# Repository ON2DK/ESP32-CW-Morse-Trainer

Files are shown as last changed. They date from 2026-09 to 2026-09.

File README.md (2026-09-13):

# ESP32 CW Morse Trainer V2

Open-source ESP32 Morse/CW trainer designed by **ON2DK**.

The ESP32 CW Morse Trainer V2 is a stand-alone Morse trainer built around a **38-pin ESP32 DevKit with ESP32-WROOM-32D**. It is intended for CW practice without connecting a transceiver.

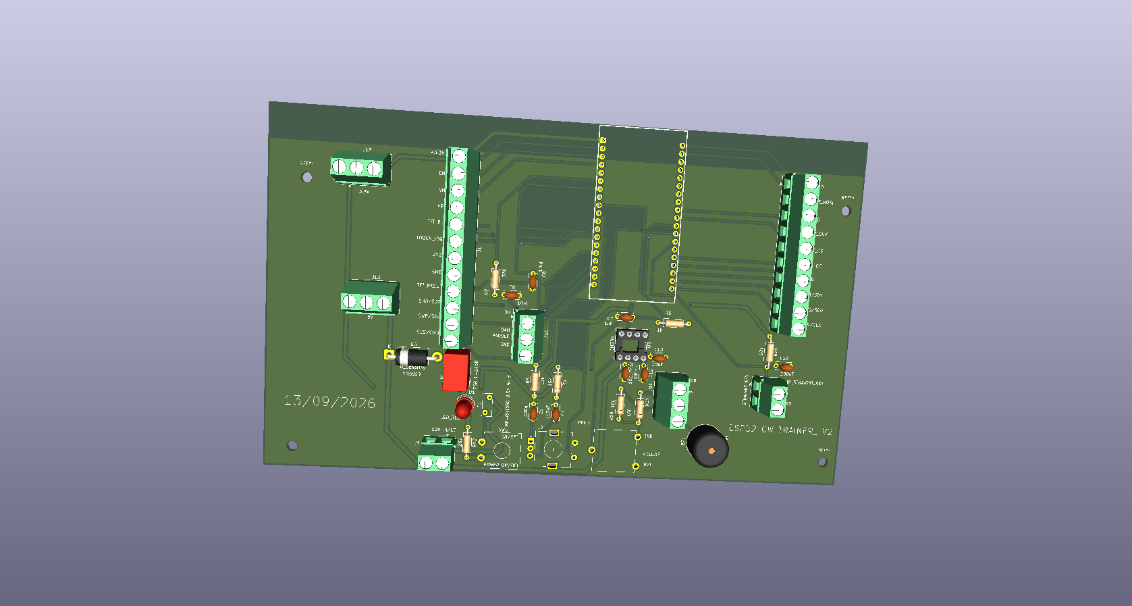
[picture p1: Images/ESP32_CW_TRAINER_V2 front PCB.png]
ESP32 CW Trainer V2 front PCB


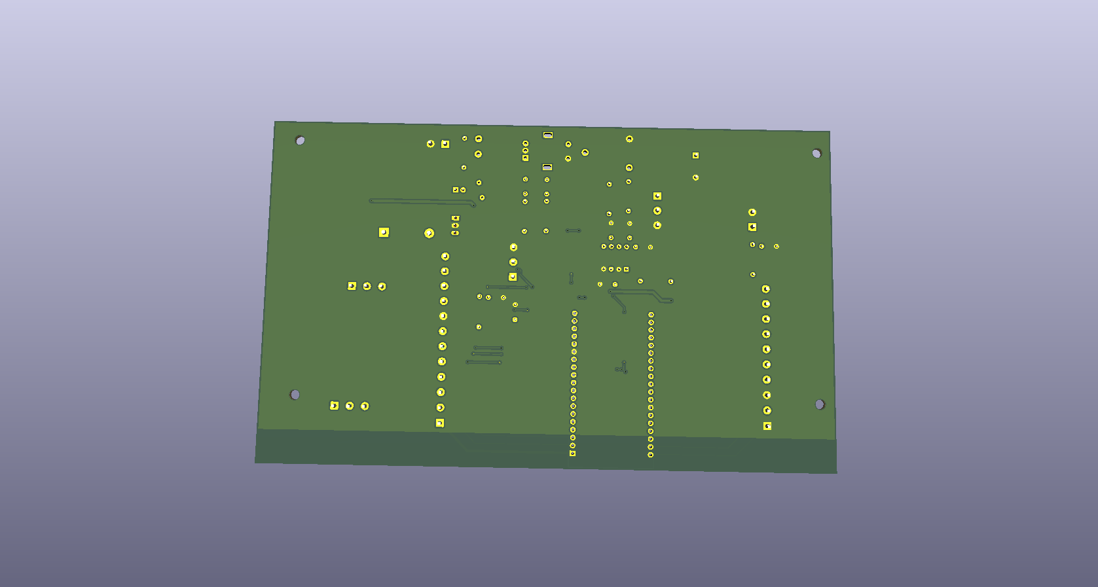
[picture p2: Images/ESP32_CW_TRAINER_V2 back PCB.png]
ESP32 CW Trainer V2 back PCB


## Main features

- 38-pin ESP32 DevKit with ESP32-WROOM-32D
- ST7789 240 x 320 SPI TFT support
- Paddle input
- Straight-key input
- Rotary encoder with push switch for menu/settings
- LM386 audio/sidetone section with buzzer
- Free CW practice
- Koch training
- Lesson selection and visible Koch characters
- Session score and total score
- Student profile/settings stored in ESP32 Preferences
- Separate 12 V DC input
- TSR 1-2450 12 V to 5 V DC/DC converter
- POWER LED on the switched 12 V supply
- USB on the ESP32 DevKit for programming
- Predominantly through-hole construction

## PCB status

The hardware design is complete and the final PCB was checked in KiCad before generating the production files.

- 2-layer PCB: F.Cu + B.Cu
- Target material: FR-4, 1.6 mm
- PCB size: approximately **189.25 x 114.50 mm**
- 4 x M3 mounting holes
- KiCad DRC: **0 violations / 0 errors / 0 warnings** at final electrical check
- Unconnected items: **0**
- Schematic/PCB parity: **0**

## Downloads and repository structure

- `KiCad/` - editable KiCad source package: `ESP32_CW_TRAINER_V2_KiCad_Source.zip`
- `Gerber/` - production package: `ESP32_CW_TRAINER_V2_Gerber.zip`
- `Firmware/` - Arduino IDE firmware and firmware notes
- `Enclosure/` - STL files for front panel, rear panel, bottom and lid, plus editable OpenSCAD source
- `Documentation/` - project logbook, BOM and build notes
- `Images/` - front and back PCB images

## Firmware

The V2 Arduino IDE firmware is available as:

- `Firmware/ESP32_CW_TRAINER_V2.ino`

The firmware has been reconciled with the definitive Trainer V2 PCB GPIO mapping and includes ST7789 display support, rotary-encoder control, paddle input, straight-key input, sidetone/audio and the existing Morse Trainer functions such as free practice, Koch training, lessons, scores and Preferences storage.

### Definitive V2 GPIO mapping

| Function | ESP32 GPIO |
|---|---:|
| TFT SCK | 18 |
| TFT MOSI | 23 |
| TFT DC | 2 |
| TFT RESET | 13 |
| TFT CS | 5 |
| TFT BACKLIGHT | 27 |
| Encoder CLK | 16 |
| Encoder DT | 17 |
| Encoder SW | 26 |
| Paddle DIT | 35 |
| Paddle DAH | 32 |
| Straight key | 4 |
| Audio / buzzer | 25 |

**GPIO35 is input-only and does not provide an internal pull-up. The Trainer V2 hardware must therefore provide the required external input bias for the DIT input.**

The current V2 firmware was successfully **compiled/verified in Arduino IDE on 13 September 2026** with **ESP32 Dev Module** selected. Arduino IDE reported approximately:

- Program storage: **1,014,070 bytes (77%)**
- Dynamic memory: **49,416 bytes (15%)**
- Dynamic memory remaining for local variables: approximately **278,264 bytes**

Successful compilation confirms that the current sketch builds with the installed ESP32/Arduino libraries. It does **not** replace practical testing on the assembled Trainer V2 PCB.

## Enclosure files

The enclosure folder contains the current mechanical design for the CW Trainer V2, including a front-panel opening for the 2.8-inch TFT so that only the display area is visible.

Current files include:

- `ESP32_CW_TRAINER_V2_Frontpaneel.stl`
- `ESP32_CW_TRAINER_V2_Achterpaneel.stl`
- `ESP32_CW_TRAINER_V2_Kast_Bodem.stl`
- `ESP32_CW_TRAINER_V2_Kast_Deksel.stl`
- `ESP32_CW_TRAINER_V2_Kast.scad`

The TFT opening should be checked against the exact physical TFT module before final printing.

## Documentation

The final project logbook with BOM is available under `Documentation/` as:

`ESP32_CW_TRAINER_V2_Projectlogboek_DEFINITIEF_MET_BOM.docx`

## Production files

Before ordering a PCB, inspect the Gerbers in a Gerber viewer and verify board outline, drill files, silkscreen, masks and both copper layers.

## Power and programming

Normal operation uses the separate **12 V DC input**. The on-board USB connector of the ESP32 DevKit is intended for programming.

During USB programming, switch the external 12 V supply **OFF**.

Power path:

`12 V DC -> 0.5 A polyfuse -> POWER switch -> TSR 1-2450 -> 5 V -> ESP32 DevKit`

The red POWER LED is connected to the switched 12 V side, so it only lights when the main power switch is ON.

## Important build notes

Always compare the physical pinout and dimensions of purchased components with the KiCad footprints before soldering. In particular, check polarity of LEDs, diodes and electrolytic capacitors, connector orientation and pin order, transistor pinouts, ESP32 DevKit orientation and clear space around the ESP32 antenna area.

Test the 5 V supply before fitting sensitive modules such as the ESP32 and TFT.

## Project status

- Hardware V2: complete / production files prepared
- KiCad electrical checks: passed
- Enclosure: available; final TFT fit to be verified
- Documentation/BOM: available
- V2 firmware: compiles successfully with definitive GPIO mapping
- Practical assembled-PCB firmware/hardware testing: pending

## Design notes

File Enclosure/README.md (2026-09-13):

# Enclosure

This folder is reserved for the 3D-printable enclosure and OpenSCAD source files for the ESP32 CW Morse Trainer V2.

The PCB uses four M3 mounting holes. Before printing a final enclosure, verify the exact dimensions of the physical TFT module, panel connectors, rotary encoder and potentiometer.

The ESP32 antenna area should remain clear of metal and dense wiring inside the enclosure.

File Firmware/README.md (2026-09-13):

# Firmware

Arduino IDE firmware for the ESP32 CW Morse Trainer belongs in this folder.

The hardware is intended for a 38-pin ESP32 DevKit with ESP32-WROOM-32D and an ST7789 240 x 320 SPI TFT.

Before flashing any sketch, verify that its GPIO definitions match the final KiCad PCB revision. Hardware and firmware should always be treated as a matched pair.

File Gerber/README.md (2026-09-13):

# Gerber production files

Current production package:

`ESP32_CW_TRAINER_V2_Gerber.zip`

The package is intended for a 2-layer FR-4 PCB and should contain the copper, solder mask, silkscreen, board outline and drill files required for fabrication.

Before ordering, inspect the archive in a Gerber viewer and verify the board outline, connector labels, mounting holes and PTH/NPTH drill data.

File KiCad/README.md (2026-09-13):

# KiCad source

This folder contains the editable KiCad source package for the ESP32 CW Morse Trainer V2.

Current source archive:

`ESP32_CW_TRAINER_V2_KiCad_Source.zip`

The project uses a 38-pin ESP32 DevKit with ESP32-WROOM-32D. When opening the project on another computer, verify that project-local footprint libraries are available and that KiCad does not replace intentionally selected footprints without review.

After any PCB edit, refill copper zones and rerun DRC and schematic/PCB parity checks before regenerating Gerbers.

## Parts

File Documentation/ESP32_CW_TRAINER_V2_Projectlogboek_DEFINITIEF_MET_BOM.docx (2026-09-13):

PROJECTLOGBOEK
ESP32 CW MORSE TRAINER V2

Definitieve hardware-revisie • 13 september 2026

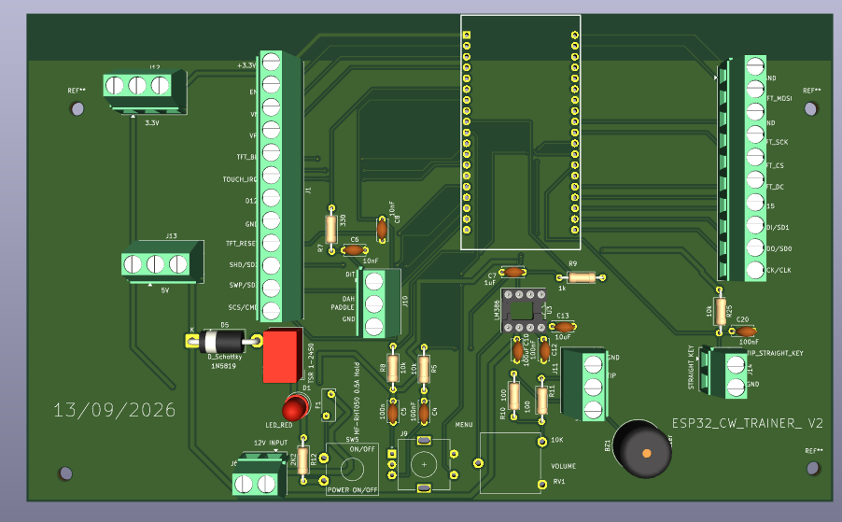
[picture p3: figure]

# 1. Projectdoel

Zelfstandige CW/Morse-trainer rond een 38-pins ESP32 DevKit met ESP32-WROOM-32D. De print ondersteunt TFT, rotary encoder/menu, paddle, straight key en audio via LM386/buzzer. De normale voeding gebeurt via een afzonderlijke 12 V ingang; USB-C op de DevKit is bedoeld voor programmeren.

# 2. Productiestatus

Controle | Status
PCB DRC | 0 overtredingen / 0 fouten / 0 waarschuwingen
Niet-verbonden items | 0
Schema-pariteit | 0
PCB-afmeting | 189,25 × 114,50 mm
Montagegaten | 4 × M3
Silkscreen | ESP32_CW_TRAINER_V2 • 13/09/2026
Gerberpakket | Definitieve F/B Cu, mask, silkscreen, Edge.Cuts, PTH en NPTH

# 3. Laatste PCB-revisie

Na het eerdere logboek zijn de projectbenaming op de PCB-silkscreen geplaatst en BZ1 (buzzer) verplaatst om de aansluiting beter bereikbaar te maken. De nieuwe PCB-afbeeldingen en productiebestanden horen bij deze revisie.

# 4. Voeding en programmering

12 V DC → F1 0,5 A polyfuse → POWER ON/OFF → TSR 1-2450 → 5 V naar de ESP32 DevKit. De rode POWER-led zit op de geschakelde 12 V zijde via R12 = 2,2 kΩ. Tijdens programmeren via USB wordt de 12 V hoofdvoeding uitgeschakeld.

# 5. ESP32-signaaltoewijzing

Functie | GPIO
TFT_DC | GPIO2
STRAIGHT_KEY | GPIO4
TFT_CS | GPIO5
TFT_RESET | GPIO13
TOUCH_IRQ | GPIO14
ENC_A / ENC_B | GPIO16 / GPIO17
TFT_SCK / TFT_MOSI | GPIO18 / GPIO23
AUDIO | GPIO25
ENC_SW | GPIO26
TFT_BL | GPIO27
DAH / DIT | GPIO32 / GPIO35
BUTTON_ADC | GPIO34

# PCB-achterzijde

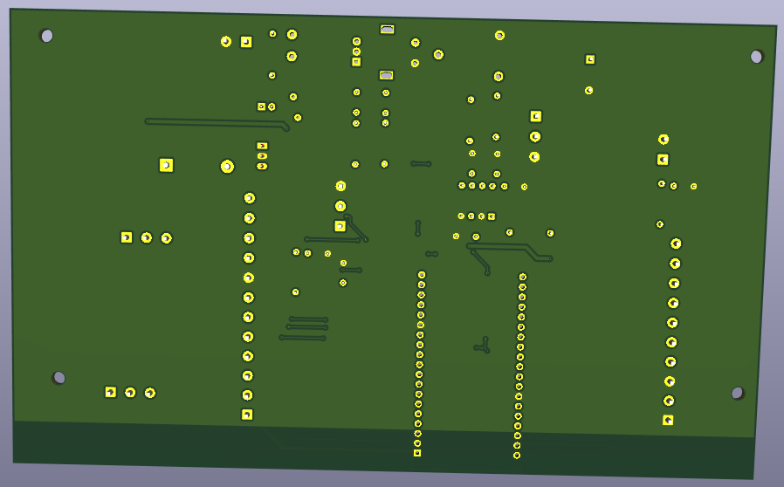
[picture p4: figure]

Definitieve 3D-weergave van de onderzijde van de ESP32 CW Morse Trainer V2.

# 6. Behuizing en assemblage

Het 3D-printbare kastpakket bevat bodem, deksel, frontpaneel, achterpaneel en OpenSCAD-bron. Controleer de werkelijk aangekochte paneelconnectoren mechanisch vóór de definitieve print. Test eerst de 5 V voeding zonder ESP32, plaats daarna de DevKit en test TFT, encoder, paddle/straight key en audio stapsgewijs.

# 7. Archivering

Bewaar samen: definitieve KiCad-bronbestanden, projectlokale ESP32_DevKit-footprintbibliotheek, Gerber/Drill-pakket, dit logboek, kastbestanden en de voor-/achteraanzichtafbeeldingen.

# 8. Componentenlijst (BOM)

Componentenlijst volgens het KiCad-schema. Controleer vóór assemblage de fysieke afmetingen en pinout van het werkelijk aangekochte onderdeel tegen de gekozen footprint.

Aantal | Referentie(s) | Waarde / onderdeel | KiCad-footprint
1 | BZ1 | Buzzer | Buzzer_Beeper:Buzzer_12x9.5RM7.6
1 | C4 | 100nF | Capacitor_THT:C_Disc_D5.0mm_W2.5mm_P5.00mm
1 | C5 | 100n | Capacitor_THT:C_Disc_D5.0mm_W2.5mm_P5.00mm
2 | C6, C8 | 10nF | Capacitor_THT:C_Disc_D5.0mm_W2.5mm_P5.00mm
1 | C7 | 1uF | Capacitor_THT:C_Disc_D5.0mm_W2.5mm_P5.00mm
1 | C10 | 100uF | Capacitor_THT:C_Disc_D5.0mm_W2.5mm_P5.00mm
1 | C12 | 100nF | Capacitor_THT:C_Disc_D5.0mm_W2.5mm_P5.00mm
1 | C13 | 10uF | Capacitor_THT:C_Disc_D5.0mm_W2.5mm_P5.00mm
1 | C20 | 100nF | Capacitor_THT:C_Disc_D5.0mm_W2.5mm_P5.00mm
1 | D1 | LED_RED | LED_THT:LED_D5.0mm
1 | D5 | 1N5819 Schottky | Diode_THT:D_DO-201AD_P15.24mm_Horizontal
1 | F1 | MF-RHT050 0.5A Hold | Fuse:Fuse_Bourns_MF-RHT050
1 | J1 | Conn_01x12 | TerminalBlock_Phoenix:MKDS-1,5-12_1x12_P5.00mm_Horizontal
1 | J3 | Conn_01x10 | TerminalBlock_Phoenix:MKDS-1,5-10_1x10_P5.00mm_Horizontal
2 | J6, J14 | Conn_01x02 | TerminalBlock_Phoenix:MKDS-1,5-2_1x02_P5.00mm_Horizontal
1 | J9 | RotaryEncoder_Switch | Rotary_Encoder:RotaryEncoder_Alps_EC11E-Switch_Vertical_H20mm
4 | J10, J11, J12, J13 | Conn_01x03 | TerminalBlock_Phoenix:MKDS-1,5-3_1x03_P5.00mm_Horizontal
3 | R5, R8, R25 | 10k | Resistor_THT:R_Axial_DIN0207_L6.3mm_D2.5mm_P10.16mm_Horizontal
1 | R7 | 330 | Resistor_THT:R_Axial_DIN0207_L6.3mm_D2.5mm_P10.16mm_Horizontal
1 | R9 | 1k | Resistor_THT:R_Axial_DIN0207_L6.3mm_D2.5mm_P10.16mm_Horizontal
2 | R10, R11 | 100 | Resistor_THT:R_Axial_DIN0207_L6.3mm_D2.5mm_P10.16mm_Horizontal
1 | R12 | 2K2 | Resistor_THT:R_Axial_DIN0207_L6.3mm_D2.5mm_P10.16mm_Horizontal
1 | RV1 | 10K | Potentiometer_THT:Potentiometer_ACP_CA14V-15_Vertical
1 | SW5 | POWER ON/OFF | Button_Switch_THT:SW_CW_GPTS203211B
1 | U2 | ESP32-WROOM-32 / 38-pin DevKit | ESP32_DevKit:ESP32_DevKit_38P
1 | U3 | LM386 | Package_DIP:DIP-8_W7.62mm_Socket
1 | U6 | TSR 1-2450 | Converter_DCDC:Converter_DCDC_TRACO_TSR-1_THT

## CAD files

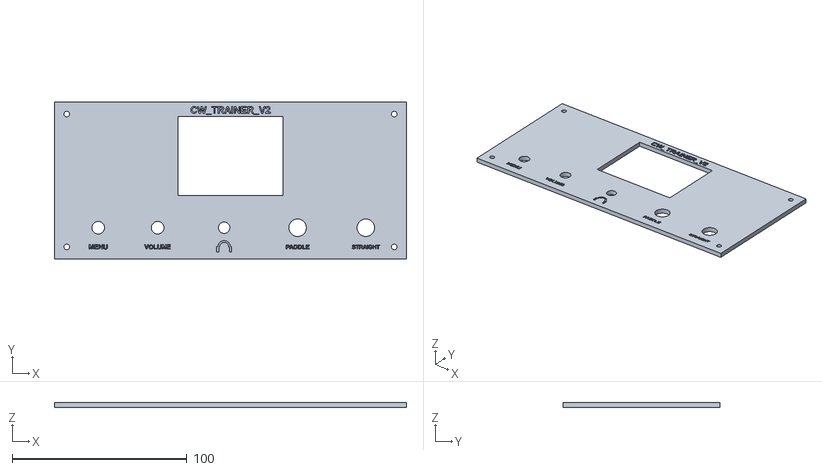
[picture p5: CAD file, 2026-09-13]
Enclosure/ESP32_CW_TRAINER_V2_Frontpaneel.stl
201.2 x 90.0 x 3.00

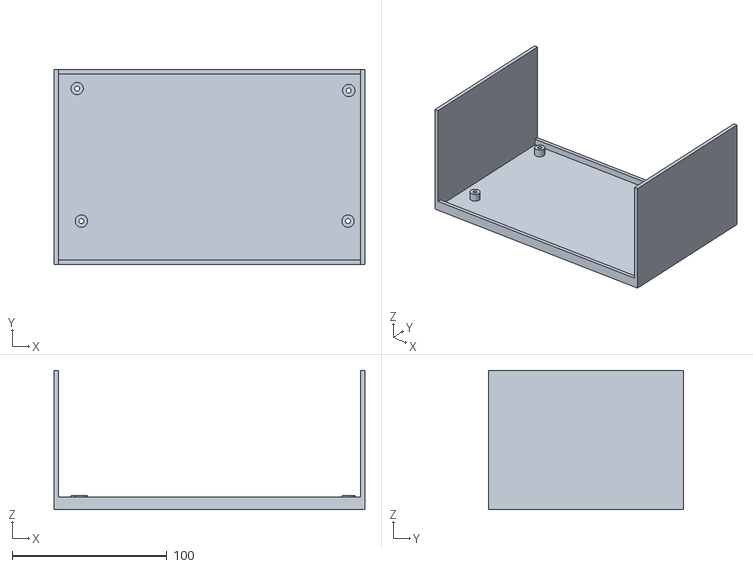
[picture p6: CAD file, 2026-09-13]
Enclosure/ESP32_CW_TRAINER_V2_Kast_Bodem.stl
201.2 x 126.5 x 90.0

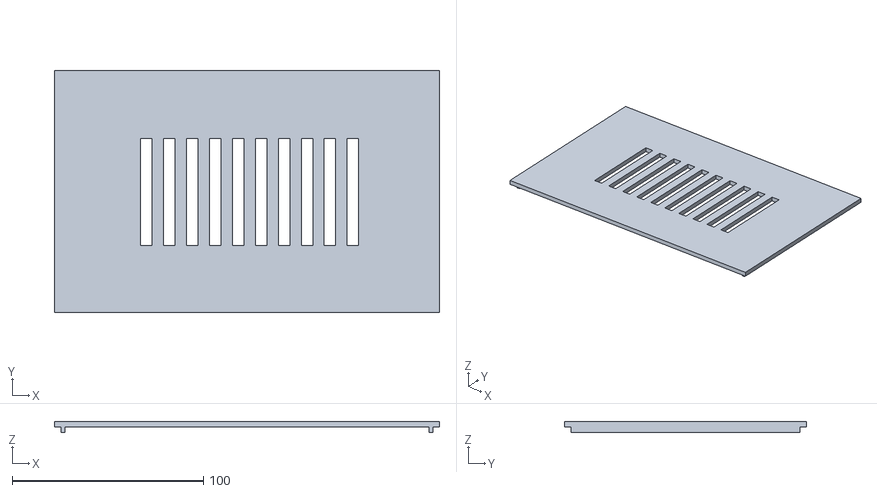
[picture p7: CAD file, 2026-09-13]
Enclosure/ESP32_CW_TRAINER_V2_Kast_Deksel.stl
201.2 x 126.5 x 6.00

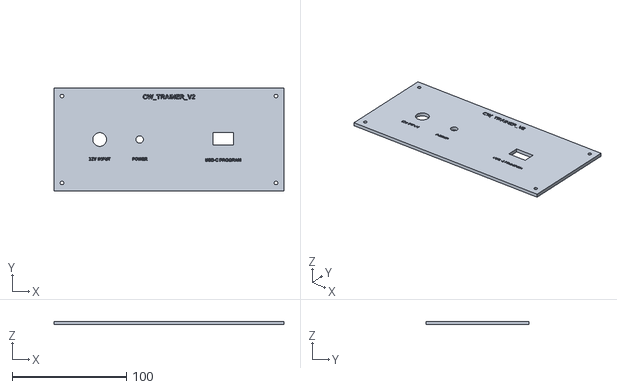
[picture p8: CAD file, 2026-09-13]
Enclosure/ESP32_CW_TRAINER_V2_Achterpaneel.stl
201.2 x 90.0 x 3.00

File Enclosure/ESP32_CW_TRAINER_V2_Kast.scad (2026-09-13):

$fn=72;

// ESP32 CW TRAINER V2 enclosure - revised front/rear panels
// TFT window is PARAMETRIC. Default 60 x 45 mm; verify against exact visible glass area.
pcb_w=189.25;
pcb_d=114.50;
clear=6;
wall=3;
bottom=3;
outer_w=pcb_w+2*clear;   // 201.25 mm
outer_d=pcb_d+2*clear;   // 126.50 mm
case_h=90;
panel_t=3;

tft_win_w=60.0;
tft_win_h=45.0;
tft_x=outer_w/2;
tft_y=59;
ctrl_y=18;

module base(){
    difference(){
        union(){
            cube([outer_w,outer_d,bottom]);
            cube([wall,outer_d,case_h]);
            translate([outer_w-wall,0,0]) cube([wall,outer_d,case_h]);
            cube([outer_w,wall,bottom+5]);
            translate([0,outer_d-wall,0]) cube([outer_w,wall,bottom+5]);
            for(p=[[9,108],[184.25,22.25],[11.75,22.25],[184.75,106.75]])
                translate([clear+p[0],clear+p[1],bottom]) cylinder(h=6,d=8);
        }
        for(p=[[9,108],[184.25,22.25],[11.75,22.25],[184.75,106.75]])
            translate([clear+p[0],clear+p[1],-0.1]) cylinder(h=bottom+6.2,d=3.2);
    }
}

module lid(){
    difference(){
        union(){
            cube([outer_w,outer_d,3]);
            translate([wall+0.4,wall+0.4,-3]) cube([2,outer_d-2*(wall+0.4),3]);
            translate([outer_w-wall-2.4,wall+0.4,-3]) cube([2,outer_d-2*(wall+0.4),3]);
        }
        for(x=[45:12:155]) translate([x,35,-0.1]) cube([6,56,3.2]);
    }
}

module engrave(txt,x,y,size=3.2) {
    translate([x,y,panel_t-0.7]) linear_extrude(height=0.8)
        text(txt,size=size,halign="center",valign="center",font="Liberation Sans:style=Bold");
}

module headphone_icon(x,y,s=1) {
    translate([x,y,panel_t-0.7]) linear_extrude(height=0.8) scale([s,s]) {
        union() {
            difference() {
                circle(r=5.0);
                circle(r=3.6);
                translate([-6,-6]) square([12,6]);
            }
            translate([-5.1,-1.8]) square([1.8,4.5],center=true);
            translate([ 5.1,-1.8]) square([1.8,4.5],center=true);
        }
    }
}

module front_panel(){
    difference(){
        cube([outer_w,case_h,panel_t]);

        translate([tft_x-tft_win_w/2,tft_y-tft_win_h/2,-0.1])
            cube([tft_win_w,tft_win_h,panel_t+0.2]);

        // Bottom row: MENU / VOLUME / HEADPHONE / PADDLE / STRAIGHT
        translate([25,ctrl_y,-0.1]) cylinder(h=panel_t+0.2,d=7.2);
        translate([59,ctrl_y,-0.1]) cylinder(h=panel_t+0.2,d=7.2);
        translate([97,ctrl_y,-0.1]) cylinder(h=panel_t+0.2,d=6.5);
        translate([139,ctrl_y,-0.1]) cylinder(h=panel_t+0.2,d=10);
        translate([178,ctrl_y,-0.1]) cylinder(h=panel_t+0.2,d=10);

        for(x=[7,outer_w-7]) for(z=[7,case_h-7])
            translate([x,z,-0.1]) cylinder(h=panel_t+0.2,d=3.2);

        engrave("CW_TRAINER_V2",outer_w/2,85,4.0);
        engrave("MENU",25,7,2.8);
        engrave("VOLUME",59,7,2.6);
        headphone_icon(97,7,0.72);
        engrave("PADDLE",139,7,2.5);
        engrave("STRAIGHT",178,7,2.3);
    }
}

module rear_panel(){
    difference(){
        cube([outer_w,case_h,panel_t]);
        translate([40,45,-0.1]) cylinder(h=panel_t+0.2,d=12);     // 12V input
        translate([75,45,-0.1]) cylinder(h=panel_t+0.2,d=6.5);    // power switch
        translate([139,40,-0.1]) cube([18,11,panel_t+0.2]);        // USB-C
        for(x=[7,outer_w-7]) for(z=[7,case_h-7])
            translate([x,z,-0.1]) cylinder(h=panel_t+0.2,d=3.2);

        engrave("CW_TRAINER_V2",outer_w/2,82,4.0);
        engrave("12V INPUT",40,28,2.8);
        engrave("POWER",75,28,2.6);
        engrave("USB-C PROGRAM",148,27,2.7);
    }
}

// Uncomment ONE line for interactive preview if desired:
// base();
// lid();
// front_panel();
// rear_panel();

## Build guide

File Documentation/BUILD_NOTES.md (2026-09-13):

# Build notes - ESP32 CW Morse Trainer V2

## Recommended assembly order

1. Inspect the bare PCB and confirm there are no damaged tracks or plated holes.
2. Fit low-profile resistors and diodes first.
3. Fit capacitors and other small components.
4. Fit IC sockets and the LM386 section.
5. Fit the TSR 1-2450 DC/DC converter.
6. Fit headers, screw terminals, encoder and other taller parts.
7. Fit the buzzer last if this makes access easier during soldering.
8. Inspect all solder joints before applying power.

## First power-up

Do not install the ESP32 DevKit or TFT for the first supply check.

- Check for shorts between supply rails and GND.
- Apply 12 V through the normal input.
- Switch the main POWER switch ON.
- Verify the switched 12 V rail.
- Verify the 5 V output of the TSR 1-2450.
- Confirm the POWER LED behaves as expected.

Only after the power rails are correct should the ESP32 DevKit and display be connected.

## Programming

The USB connector on the ESP32 DevKit is used for programming. Keep the external 12 V supply switched OFF while programming through USB.

## Mechanical checks

Before final enclosure assembly:

- confirm the four M3 mounting positions;
- keep the ESP32 antenna area clear of metal and wiring;
- check connector access;
- verify the actual TFT module dimensions before cutting or printing a display window.

## Production check

Before ordering boards, open the Gerber package in a viewer and inspect:

- F.Cu and B.Cu;
- F.Mask and B.Mask;
- silkscreen text and connector labels;
- Edge.Cuts;
- PTH and NPTH drill files.

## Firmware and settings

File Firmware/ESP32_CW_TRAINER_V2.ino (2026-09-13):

/*
  ON2DK ESP32 CW TRAINER V2 - Morse Trainer Pro v3.3.0
  --------------------------------
  Eerste stabiele basisversie met:
  - ST7789 320x240 landscape
  - Hoofdmenu
  - Vrij oefenen
  - Koch-training
  - Instellingen
  - Cursistprofiel in ESP32 Preferences
  - Sessiescore en totaalscore
  - Leskeuze met zichtbare Koch-tekens
  - Na een geslaagde sessie keuze: volgende les / herhalen / kiezen
  - Niet-blokkerende morseweergave
  - Betrouwbare paddle-invoer zonder dubbele tekens

  Libraries:
  - Adafruit GFX Library
  - Adafruit ST7789
  - Adafruit BusIO
  - ESP32Encoder

  Definitieve ESP32 CW TRAINER V2 pinnen:
  TFT SCK         GPIO18
  TFT MOSI        GPIO23
  TFT DC          GPIO2
  TFT RESET       GPIO13
  TFT CS          GPIO5
  TFT BACKLIGHT   GPIO27

  Encoder CLK     GPIO16
  Encoder DT      GPIO17
  Encoder SW      GPIO26

  Paddle DIT      GPIO35
  Paddle DAH      GPIO32
  Straight key    GPIO4

  Audio/Buzzer    GPIO25
*/

#include <SPI.h>
#include <Adafruit_GFX.h>
#include <Adafruit_ST7789.h>
#include <ESP32Encoder.h>
#include <Preferences.h>

// -----------------------------------------------------------------------------
// CW TRAINER V2 display colours
// These aliases preserve the colour names used throughout the original trainer.
// -----------------------------------------------------------------------------
#define C_BG       ST77XX_BLACK
#define C_PANEL    ST77XX_BLACK
#define C_WHITE    ST77XX_WHITE
#define C_GREY     0x8410
#define C_DARKGREY 0x4208
#define C_ORANGE   0xFD20
#define C_GREEN    ST77XX_GREEN
#define C_RED      ST77XX_RED
#define C_AMBER    0xFBE0

#include <WiFi.h>
#include <WebServer.h>

// ============================================================
// HARDWARE
// ============================================================

#define TFT_SCK         18
#define TFT_MOSI        23
#define TFT_DC           2
#define TFT_RST         13
#define TFT_CS           5
#define TFT_BACKLIGHT   27

#define BUZZER_PIN      25
#define PADDLE_DIT      35
#define PADDLE_DAH      32
#define STRAIGHT_KEY     4

#define ENCODER_CLK     16
#define ENCODER_DT      17
#define ENCODER_SW      26

Adafruit_ST7789 tft = Adafruit_ST7789(TFT_CS, TFT_DC, TFT_RST);
ESP32Encoder encoder;
Preferences prefs;
WebServer webServer(80);

// ============================================================
// KLEUREN
// ============================================================
#define C_PANEL       0x0000
#define C_BLACK       0x0000
#define C_BLUE        0x001F
#define C_RED         0xF800
#define C_GREEN       0x07E0
#define C_CYAN        0x07FF
#define C_MAGENTA     0xF81F
#define C_YELLOW      0xFFE0
#define C_WHITE       0xFFFF

// color definitions TFT7789
const uint16_t  Display_Color_Black        = 0x0000;
const uint16_t  Display_Color_Blue         = 0x001F;
const uint16_t  Display_Color_Red          = 0xF800;
const uint16_t  Display_Color_Green        = 0x07E0;
const uint16_t  Display_Color_Cyan         = 0x07FF;
const uint16_t  Display_Color_Magenta      = 0xF81F;
const uint16_t  Display_Color_Yellow       = 0xFFE0;
const uint16_t  Display_Color_White        = 0xFFFF;

// ============================================================
// MORSE-DATABASE
// ============================================================

struct MorseEntry {
  char symbol;
  const char* code;
};

const MorseEntry morseTable[] = {
  {'A', ".-"}, {'B', "-..."}, {'C', "-.-."}, {'D', "-.."},
  {'E', "."}, {'F', "..-."}, {'G', "--."}, {'H', "...."},
  {'I', ".."},{'J', ".---"}, {'K', "-.-"}, {'L', ".-.."},
  {'M', "--"},{'N', "-."}, {'O', "---"}, {'P', ".--."},
  {'Q', "--.-"}, {'R', ".-."}, {'S', "..."}, {'T', "-"},
  {'U', "..-"}, {'V', "...-"}, {'W', ".--"}, {'X', "-..-"},
  {'Y', "-.--"}, {'Z', "--.."},
  {'1', ".----"}, {'2', "..---"}, {'3', "...--"}, {'4', "....-"},
  {'5', "....."}, {'6', "-...."}, {'7', "--..."}, {'8', "---.."},
  {'9', "----."}, {'0', "-----"}, 
  {'.',".-.-.-"}, {',',"--..--"}, {'?',"..--.."}, {'/',"-..-."}, 
  {'=',"-...-"}, {'+',".-.-."}, {'-',"-....-"}, {'(',"-.--."},
  {')',"-.--.-"}, {'@',".--.-."},
 
};

const int MORSE_COUNT = sizeof(morseTable) / sizeof(morseTable[0]);

/*
  Eerste programmeerbare Koch-profiel.
  De eerste les bevat K en M. Elk volgend niveau voegt één teken toe.

  Deze reeks kan later via SD/webinterface gewijzigd worden zonder
  de trainingsengine opnieuw te schrijven.
*/
const char KOCH_ORDER[] =
 "KMRSUAPTOWNJEFLVGHDBXZQYC1234567890.,?/=+()@-";

const int KOCH_CHAR_COUNT = sizeof(KOCH_ORDER) - 1;

// ============================================================
// INSTELLINGEN EN PROFIEL
// ============================================================

struct TrainerSettings {
  int wpm = 18;
  int revealDelaySec = 2;
  int toneHz = 700;
  int sessionLength = 20;
  int promotionPercent = 90;
  int wordGapSec = 2;
  bool readyBeep = true;
};

struct StudentProfile {
  char name[16] = "Paul";
  int kochLevel = 1;        // niveau 1 = K en M
  uint32_t totalQuestions = 0;
  uint32_t totalCorrect = 0;
  uint32_t completedSessions = 0;
};

TrainerSettings settings;
StudentProfile student;

int dotMs = 1200 / 18;

// ============================================================
// APP-STATUS
// ============================================================

enum Screen {
  SCREEN_MAIN_MENU,
  SCREEN_SETTINGS,
  SCREEN_SPEED_WPM,
  SCREEN_STATISTICS,
  SCREEN_KOCH_SELECT,
  SCREEN_SESSION_MENU,
  SCREEN_FREE_KEYING,
  SCREEN_WEB_SELECT,
  SCREEN_WEB_STATUS,
  SCREEN_TRAINING
};

enum TrainingMode {
  MODE_FREE,
  MODE_KOCH
};

enum TrainingState {
  TRAIN_NEW_QUESTION,
  TRAIN_PREPARE_PLAYBACK,
  TRAIN_PLAYBACK,
  TRAIN_REVEAL_DELAY,
  TRAIN_READY_BEEP,
  TRAIN_WAIT_INPUT,
  TRAIN_CHECK_INPUT,
  TRAIN_SHOW_RESULT,
  TRAIN_SESSION_COMPLETE
};

Screen currentScreen = SCREEN_MAIN_MENU;
TrainingMode trainingMode = MODE_FREE;
TrainingState trainingState = TRAIN_NEW_QUESTION;

const char* mainMenuItems[] = {
  "Vrij oefenen",
  "Koch training",
  "Vrij seinen",
  "Statistieken",
  "Instellingen",
  "Webserver"
};
const int MAIN_MENU_COUNT = 6;

const char* settingItems[] = {
  "WPM",
  "Toonhoogte",
  "Toon vertraging",
  "Sessie lengte",
  "Promotiedrempel",
  "Startsignaal",
  "Terug"
};
const int SETTINGS_COUNT = 7;

int menuIndex = 0;
int settingsIndex = 0;
int selectedKochLesson = 1;       // les 1 bevat K en M
int sessionMenuIndex = 0;
bool editingSetting = false;
bool sessionPassed = false;

bool lastEncoderButton = HIGH;
unsigned long encoderPressedAt = 0;
bool longPressHandled = false;
unsigned long lastButtonEdgeAt = 0;

long lastEncoderRaw = 0;
int encoderPulseAccumulator = 0;
const int ENCODER_PULSES_PER_STEP = 2;  // attachHalfQuad: meestal 2 pulsen per klik
unsigned long lastEncoderStepAt = 0;
const unsigned long ENCODER_STEP_GUARD_MS = 8;

// ============================================================
// TRAININGSSTATUS
// ============================================================

int currentMorseIndex = 0;
String userMorse = "";

int sessionQuestions = 0;
int sessionCorrect = 0;

unsigned long trainingTimer = 0;
unsigned long lastPaddleActivity = 0;
bool lastAnswerCorrect = false;
String decodedText = "";
bool wordSpaceInserted = true;
bool wordGapSavePending = false;
unsigned long wordGapChangedAt = 0;

int webModeIndex = 0;
bool webRunning = false;
bool webFallbackAP = false;
bool webRoutesConfigured = false;
bool webConnectedShown = false;
unsigned long wifiConnectStartedAt = 0;
String wifiSSID = "";
String wifiPassword = "";
const char* LOCAL_AP_SSID = "ON5MB-Morse";
const char* LOCAL_AP_PASSWORD = "ON5MB2026";

// ============================================================
// MORSE-AFSPELER
// ============================================================

const char* playbackCode = nullptr;
int playbackPosition = 0;

enum PlaybackPhase {
  PLAY_IDLE,
  PLAY_TONE,
  PLAY_GAP
};

PlaybackPhase playbackPhase = PLAY_IDLE;
unsigned long playbackTimer = 0;

// ============================================================
// PADDLE-KEYER
// ============================================================

enum KeyerPhase {
  KEYER_IDLE,
  KEYER_TONE,
  KEYER_GAP
};

KeyerPhase keyerPhase = KEYER_IDLE;

// Straight-key state. The straight key is decoded by measuring how long
// the contact remains closed: shorter than 2 dot lengths = dit,
// 2 dot lengths or longer = dah.
bool straightKeyDown = false;
unsigned long straightKeyPressedAt = 0;
char keyerElement = '\0';
unsigned long keyerTimer = 0;

/*
  Belangrijk:
  - één korte tik geeft exact één element;
  - vasthouden herhaalt;
  - pas na loslaten kan een nieuwe losse tik starten;
  - geen paddle-memory die onbedoeld een tweede element veroorzaakt.

  Iambic A/B voegen we later als afzonderlijke instelbare keyermodule toe.
*/

// ============================================================
// DISPLAY-HULPFUNCTIES
// ============================================================

void centeredText(const String& text, int y, int size, uint16_t color,
  uint16_t background = C_PANEL) {
  int16_t x1, y1;
  uint16_t w, h;

  tft.setTextSize(size);
  tft.setTextColor(color, background);
  tft.getTextBounds(text, 0, y, &x1, &y1, &w, &h);
  tft.setCursor((tft.width() - w) / 2, y);
  tft.print(text);
}

void drawTopBar(const String& title) {
  tft.fillRect(0, 0, 320, 36, C_PANEL);
  tft.drawFastHLine(0, 36, 320, C_ORANGE);

  tft.setTextSize(2);
  tft.setTextColor(C_ORANGE, C_PANEL);
  tft.setCursor(8, 9);
  tft.print(title);
}

void drawFooter(const String& text) {
  tft.fillRect(0, 218, 320, 22, C_PANEL);
  tft.drawFastHLine(0, 217, 320, C_DARKGREY);
  centeredText(text, 224, 1, C_GREY, C_PANEL);
}

void clearContent() {
  tft.fillRect(0, 37, 320, 180, C_BG);
}

void drawMenuLine(int y, const String& text, bool selected) {
  uint16_t bg = selected ? C_ORANGE : C_BG;
  uint16_t fg = selected ? C_BG : C_WHITE;

  tft.fillRoundRect(22, y, 276, 32, 5, bg);
  tft.setTextSize(2);
  tft.setTextColor(fg, bg);
  tft.setCursor(36, y + 8);
  tft.print(selected ? "> " : "  ");
  tft.print(text);
}

void drawMainMenuLine(int index, bool selected) {
  int y = 40 + index * 29;
  uint16_t bg = selected ? C_ORANGE : C_BG;
  uint16_t fg = selected ? C_BG : C_WHITE;

  tft.fillRoundRect(22, y, 276, 26, 4, bg);
  tft.setTextSize(2);
  tft.setTextColor(fg, bg);
  tft.setCursor(36, y + 5);
  tft.print(selected ? "> " : "  ");
  tft.print(mainMenuItems[index]);
}

void drawSplash() {
  tft.drawRect(0, 0, 320, 240, C_ORANGE);
  tft.drawRect(4, 4, 312, 232, C_DARKGREY);

  centeredText("ON5MB", 112, 4, C_ORANGE);
  centeredText("V1.0", 178, 2, C_AMBER);

  delay(1000);
}

// ============================================================
// SCHERMEN
// ============================================================

void redrawMainMenuSelection(int oldIndex, int newIndex) {
  if (oldIndex >= 0 && oldIndex < MAIN_MENU_COUNT) {
    drawMainMenuLine(oldIndex, false);
  }
  if (newIndex >= 0 && newIndex < MAIN_MENU_COUNT) {
    drawMainMenuLine(newIndex, true);
  }
}

void drawSettingLine(int index, bool selected) {
  int y = 40 + index * 25;
  uint8_t bg = selected ? C_ORANGE : C_BG;
  uint8_t fg = selected ? C_BG : C_WHITE;

  // Wis alleen deze ene regel, niet het volledige scherm.
  tft.fillRoundRect(12, y, 296, 22, 4, bg);
  tft.setTextSize(1);
  tft.setTextColor(fg, bg);
  tft.setCursor(22, y + 7);
  tft.print(selected ? "> " : "  ");
  tft.print(settingItems[index]);

  if (index < SETTINGS_COUNT - 1) {
    // Waardegebied altijd volledig overschrijven.
    tft.fillRect(220, y + 2, 82, 18, bg);
    tft.setTextColor(fg, bg);
    tft.setCursor(224, y + 7);

    switch (index) {
      case 0:
        tft.print(settings.wpm);
        tft.print(" WPM");
        break;
      case 1:
        tft.print(settings.toneHz);
        tft.print(" Hz");
        break;
      case 2:
        tft.print(settings.revealDelaySec);
        tft.print(" s");
        break;
      case 3:
        tft.print(settings.sessionLength);
        break;
      case 4:
        tft.print(settings.promotionPercent);
        tft.print("%");
        break;
      case 5:
        tft.print(settings.readyBeep ? "Aan" : "Uit");
        break;
    }
  }
}

void redrawSettingsSelection(int oldIndex, int newIndex) {
  if (oldIndex >= 0 && oldIndex < SETTINGS_COUNT) {
    drawSettingLine(oldIndex, false);
  }
  if (newIndex >= 0 && newIndex < SETTINGS_COUNT) {
    drawSettingLine(newIndex, true);
  }
}

const char* sessionMenuLabel(int index) {
  static const char* labelsPassed[] = {
    "Volgende les",
    "Dezelfde les",
    "Andere les kiezen",
    "Hoofdmenu"
  };
  static const char* labelsFailed[] = {
    "Dezelfde les",
    "Andere les kiezen",
    "Hoofdmenu"
  };

  bool hasNext = sessionPassed && selectedKochLesson < KOCH_CHAR_COUNT - 1;
  return hasNext ? labelsPassed[index] : labelsFailed[index];
}

void redrawSessionMenuSelection(int oldIndex, int newIndex) {
  if (oldIndex >= 0) {
    drawMenuLine(88 + oldIndex * 31, sessionMenuLabel(oldIndex), false);
  }
  if (newIndex >= 0) {
    drawMenuLine(88 + newIndex * 31, sessionMenuLabel(newIndex), true);
  }
}

void redrawKochLessonContent() {
  // Alleen het veranderlijke middengebied vernieuwen.
  tft.fillRect(0, 39, 320, 178, C_BG);

  centeredText("LES " + String(selectedKochLesson), 51, 4, C_ORANGE);

  tft.setTextSize(1);
  tft.setTextColor(C_GREY, C_BG);
  tft.setCursor(18, 105);
  tft.print("Beschikbare tekens:");

  String chars = kochCharactersForLesson(selectedKochLesson);
  int split = chars.length() > 32 ? 32 : chars.length();
  if (split < chars.length()) {
    while (split > 0 && chars[split] != ' ') split--;
  }

  centeredText(chars.substring(0, split), 128, 2, C_WHITE);
  if (split < chars.length()) {
    centeredText(chars.substring(split + 1), 156, 2, C_WHITE);
  }

  tft.setTextSize(1);
  tft.setTextColor(C_GREEN, C_BG);
  tft.setCursor(18, 193);
  tft.print("Hoogste bereikte les: ");
  tft.print(student.kochLevel);
}

void drawMainMenu() {
  currentScreen = SCREEN_MAIN_MENU;
  tft.fillScreen(C_BG);
  drawTopBar("CW STUDIO ON5MB");

  for (int i = 0; i < MAIN_MENU_COUNT; i++) {
    drawMainMenuLine(i, i == menuIndex);
  }

  drawFooter("Draai = kiezen | Druk = openen");
}

void drawFreeKeying() {
  currentScreen = SCREEN_FREE_KEYING;
  tft.fillScreen(C_BG);
  drawTopBar("VRIJ SEINEN");
  centeredText("SEIN EEN TEKEN", 48, 2, C_AMBER);
  centeredText(userMorse.length() ? userMorse : "...", 84, 4,
               userMorse.length() ? C_CYAN : C_DARKGREY);
  tft.drawFastHLine(20, 132, 280, C_DARKGREY);
  centeredText(decodedText.length() ? decodedText : "Uitvoer verschijnt hier",
               151, decodedText.length() ? 3 : 1,
               decodedText.length() ? C_GREEN : C_GREY);
  centeredText("Woordpauze: " + String(settings.wordGapSec) + " s",
               198, 1, C_AMBER);
  drawFooter("Draai = pauze | Druk = wissen | Lang = terug");
}

void redrawFreeKeyingInput() {
  tft.fillRect(0, 78, 320, 48, C_BG);
  centeredText(userMorse.length() ? userMorse : "...", 84, 4,
               userMorse.length() ? C_CYAN : C_DARKGREY);
}

void redrawDecodedText() {
  tft.fillRect(0, 140, 320, 70, C_BG);
  centeredText(decodedText.length() ? decodedText : "Uitvoer verschijnt hier",
               151, decodedText.length() ? 3 : 1,
               decodedText.length() ? C_GREEN : C_GREY);
  centeredText("Woordpauze: " + String(settings.wordGapSec) + " s",
               198, 1, C_AMBER);
}

void redrawWordGapSetting() {
  tft.fillRect(0, 192, 320, 20, C_BG);
  centeredText("Woordpauze: " + String(settings.wordGapSec) + " s",
               198, 1, C_AMBER);
}

void drawWebSelect() {
  currentScreen = SCREEN_WEB_SELECT;
  tft.fillScreen(C_BG);
  drawTopBar("WEBSERVER");
  centeredText("KIES VERBINDING", 48, 2, C_AMBER);
  drawMenuLine(82, "Eigen netwerk", webModeIndex == 0);
  drawMenuLine(124, "Thuis-wifi", webModeIndex == 1);
  drawFooter("Draai = kiezen | Druk = starten");
}

void redrawWebSelect() {
  drawMenuLine(82, "Eigen netwerk", webModeIndex == 0);
  drawMenuLine(124, "Thuis-wifi", webModeIndex == 1);
}

void drawWebStatus() {
  currentScreen = SCREEN_WEB_STATUS;
  tft.fillScreen(C_BG);
  drawTopBar("WEBSERVER ACTIEF");

  if (WiFi.getMode() == WIFI_AP || webFallbackAP) {
    centeredText("Eigen wifi-netwerk", 52, 2, C_AMBER);
    centeredText(LOCAL_AP_SSID, 84, 2, C_WHITE);
    centeredText("Wachtwoord: " + String(LOCAL_AP_PASSWORD), 113, 1, C_GREY);
    centeredText("http://192.168.4.1", 143, 2, C_GREEN);
  } else if (WiFi.status() == WL_CONNECTED) {
    centeredText("Verbonden met thuis-wifi", 52, 2, C_GREEN);
    centeredText(wifiSSID, 84, 2, C_WHITE);
    centeredText("http://" + WiFi.localIP().toString(), 126, 2, C_GREEN);
  } else {
    centeredText("Verbinden met thuis-wifi...", 66, 2, C_AMBER);
    centeredText(wifiSSID, 105, 2, C_WHITE);
    centeredText("Maximaal 15 seconden", 150, 1, C_GREY);
  }

  drawFooter("Druk = stoppen | Lang = hoofdmenu");
}

void drawSettings() {
  currentScreen = SCREEN_SETTINGS;
  tft.fillScreen(C_BG);
  drawTopBar("INSTELLINGEN");

  for (int i = 0; i < SETTINGS_COUNT; i++) {
    drawSettingLine(i, i == settingsIndex);
  }

  drawFooter(editingSetting
    ? "Draai = wijzigen | Druk = bevestigen"
    : "Draai = kiezen | Druk = openen");
}

void drawStatistics() {
  currentScreen = SCREEN_STATISTICS;
  tft.fillScreen(C_BG);
  drawTopBar("STATISTIEKEN");

  tft.setTextSize(2);
  tft.setTextColor(C_ORANGE, C_BG);
  tft.setCursor(18, 50);
  tft.print(student.name);

  uint32_t accuracy = student.totalQuestions == 0
    ? 0
    : (student.totalCorrect * 100UL) / student.totalQuestions;

  tft.setTextSize(2);
  tft.setTextColor(C_WHITE, C_BG);

  tft.setCursor(18, 85);
  tft.print("Koch niveau:");
  tft.setCursor(230, 85);
  tft.print(student.kochLevel);

  tft.setCursor(18, 115);
  tft.print("Vragen:");
  tft.setCursor(230, 115);
  tft.print(student.totalQuestions);

  tft.setCursor(18, 145);
  tft.print("Juist:");
  tft.setCursor(230, 145);
  tft.print(student.totalCorrect);

  tft.setCursor(18, 175);
  tft.print("Score:");
  tft.setCursor(230, 175);
  tft.setTextColor(accuracy >= 90 ? C_GREEN : C_AMBER, C_BG);
  tft.print(accuracy);
  tft.print("%");

  drawFooter("Druk = terug");
}

void drawTrainingHeader() {
  tft.fillRect(0, 0, 320, 38, C_PANEL);
  tft.drawFastHLine(0, 38, 320, C_ORANGE);

  tft.setTextSize(1);
  tft.setTextColor(C_ORANGE, C_PANEL);
  tft.setCursor(8, 7);
  tft.print(trainingMode == MODE_KOCH ? "KOCH TRAINING" : "VRIJ OEFENEN");

  tft.setTextColor(C_WHITE, C_PANEL);
  tft.setCursor(8, 23);
  tft.print("WPM ");
  tft.print(settings.wpm);

  if (trainingMode == MODE_KOCH) {
    tft.setCursor(82, 23);
    tft.print("LES ");
    tft.print(selectedKochLesson);
  }

  tft.setCursor(164, 23);
  tft.print("SCORE ");
  tft.print(sessionCorrect);
  tft.print("/");
  tft.print(sessionQuestions);

  tft.setCursor(265, 23);
  tft.print("/");
  tft.print(settings.sessionLength);
}

void drawListening() {
  tft.fillScreen(C_BG);
  drawTrainingHeader();

  centeredText("LUISTER", 65, 2, C_AMBER);
  centeredText("?", 97, 7, C_ORANGE);

  if (trainingMode == MODE_KOCH) {
    String available = "Tekens: ";
    int count = min(selectedKochLesson + 1, KOCH_CHAR_COUNT);

    for (int i = 0; i < count && i < 12; i++) {
      available += KOCH_ORDER[i];
      available += " ";
    }

    centeredText(available, 198, 1, C_GREY);
  }

  drawFooter("Lang drukken = sessie stoppen");
}

void drawAnswerPrompt() {
  tft.fillScreen(C_BG);
  drawTrainingHeader();

  centeredText("SEIN HET TEKEN", 48, 2, C_AMBER);

  String symbolText = String(morseTable[currentMorseIndex].symbol);
  centeredText(symbolText, 78, 7, C_ORANGE);
  centeredText(String(morseTable[currentMorseIndex].code), 151, 3, C_WHITE);

  tft.drawFastHLine(25, 191, 270, C_DARKGREY);

  if (userMorse.length() == 0) {
    centeredText("Paddle: DIT / DAH", 201, 1, C_GREY);
  } else {
    centeredText(userMorse, 196, 3, C_CYAN);
  }
}

void drawPaddleInput() {
  tft.fillRect(0, 194, 320, 23, C_BG);

  if (userMorse.length() == 0) {
    centeredText("Paddle: DIT / DAH", 201, 1, C_GREY);
  } else {
    centeredText(userMorse, 196, 3, C_CYAN);
  }
}

void drawTrainingResult(bool correct) {
  tft.fillRect(0, 185, 320, 32, C_BG);
  centeredText(correct ? "GOED!" : "FOUT!",
               190, 3, correct ? C_GREEN : C_RED);
}

String kochCharactersForLesson(int lesson) {
  int count = constrain(lesson + 1, 2, KOCH_CHAR_COUNT);
  String result = "";
  for (int i = 0; i < count; i++) {
    result += KOCH_ORDER[i];
    if (i < count - 1) result += " ";
  }
  return result;
}

void drawKochSelect() {
  currentScreen = SCREEN_KOCH_SELECT;
  tft.fillScreen(C_BG);
  drawTopBar("KIES KOCH-LES");

  centeredText("LES " + String(selectedKochLesson), 51, 4, C_ORANGE);

  tft.setTextSize(1);
  tft.setTextColor(C_GREY, C_BG);
  tft.setCursor(18, 105);
  tft.print("Beschikbare tekens:");

  String chars = kochCharactersForLesson(selectedKochLesson);
  int split = chars.length() > 32 ? 32 : chars.length();
  if (split < chars.length()) {
    while (split > 0 && chars[split] != ' ') split--;
  }

  centeredText(chars.substring(0, split), 128, 2, C_WHITE);
  if (split < chars.length()) {
    centeredText(chars.substring(split + 1), 156, 2, C_WHITE);
  }

  tft.setTextSize(1);
  tft.setTextColor(C_GREEN, C_BG);
  tft.setCursor(18, 193);
  tft.print("Hoogste bereikte les: ");
  tft.print(student.kochLevel);

  drawFooter("Draai = les kiezen | Druk = starten");
}
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
void loop() {
  updateEncoderButton();

  if (webRunning) {
    updateWebServer();
  }

  if (currentScreen == SCREEN_FREE_KEYING) {
    updateFreeKeying();
    handleEncoderRotation();
  } else if (currentScreen != SCREEN_TRAINING) {
    handleEncoderRotation();
  } else {
    updateTraining();
  }
}

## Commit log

2026-09-13 Document Trainer KiCad files
2026-09-13 Document Trainer Gerber files
2026-09-13 Add Trainer enclosure notes
2026-09-13 Add files via upload
    Add final CW Trainer V2 enclosure files
    [ESP32_CW_TRAINER_V2_Achterpaneel.stl, ESP32_CW_TRAINER_V2_Frontpaneel.stl, ESP32_CW_TRAINER_V2_Kast.scad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]
2026-09-13 Fix Trainer enclosure source filename in README
